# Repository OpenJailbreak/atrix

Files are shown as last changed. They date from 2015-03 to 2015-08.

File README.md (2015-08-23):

# Atrix v1.0.2
Atrix is an open source project based around iPhone/iPad/iPod 30pin to serial adapter or breakout hardware.

Two subprojects exsist;

Atrix half breakout - just gives you a small piece of hardware that just breaks out USB for sync and serial for uses such as on device kernel debugging. This is more of a BYOB (bring your own board) project as you'll need to provide your own serial converter such as an FTDI Basic, or the similar. 

Atrix full breakout (TODO) - gives you all 30 pins broken out just like a PodBreakout would.  

Atrix adapter - gives you everything you need in one package, FTDI and USB all on one board for convenience.

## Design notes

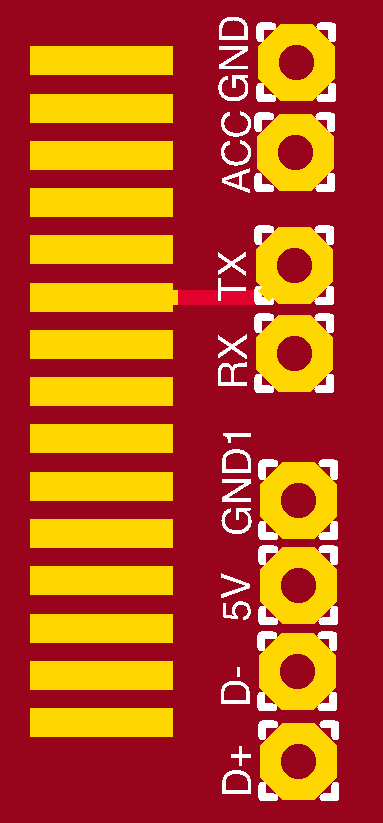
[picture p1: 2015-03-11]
breakout/mockups/Atrix_breakout_board_top.png

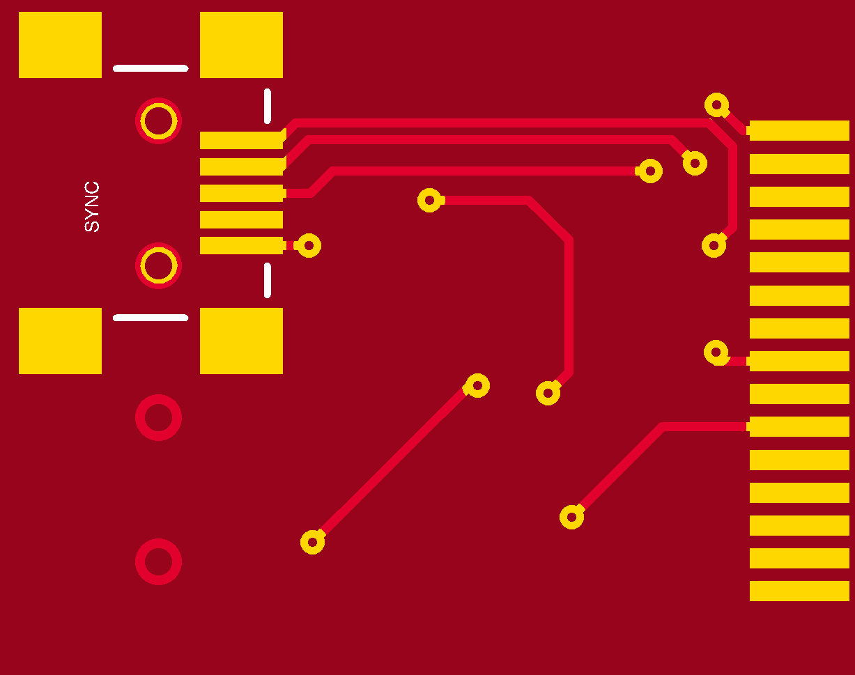
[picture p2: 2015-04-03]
adapter/mockups/eagleUp_Atrix_adapter_board_bottom.png

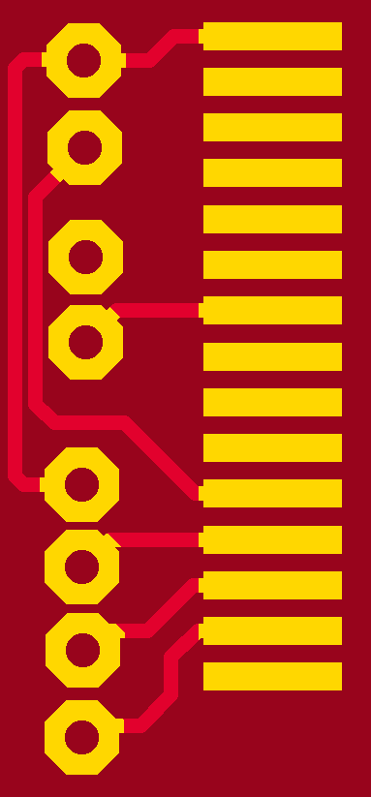
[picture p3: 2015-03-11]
breakout/mockups/Atrix_breakout_board_bottom.png

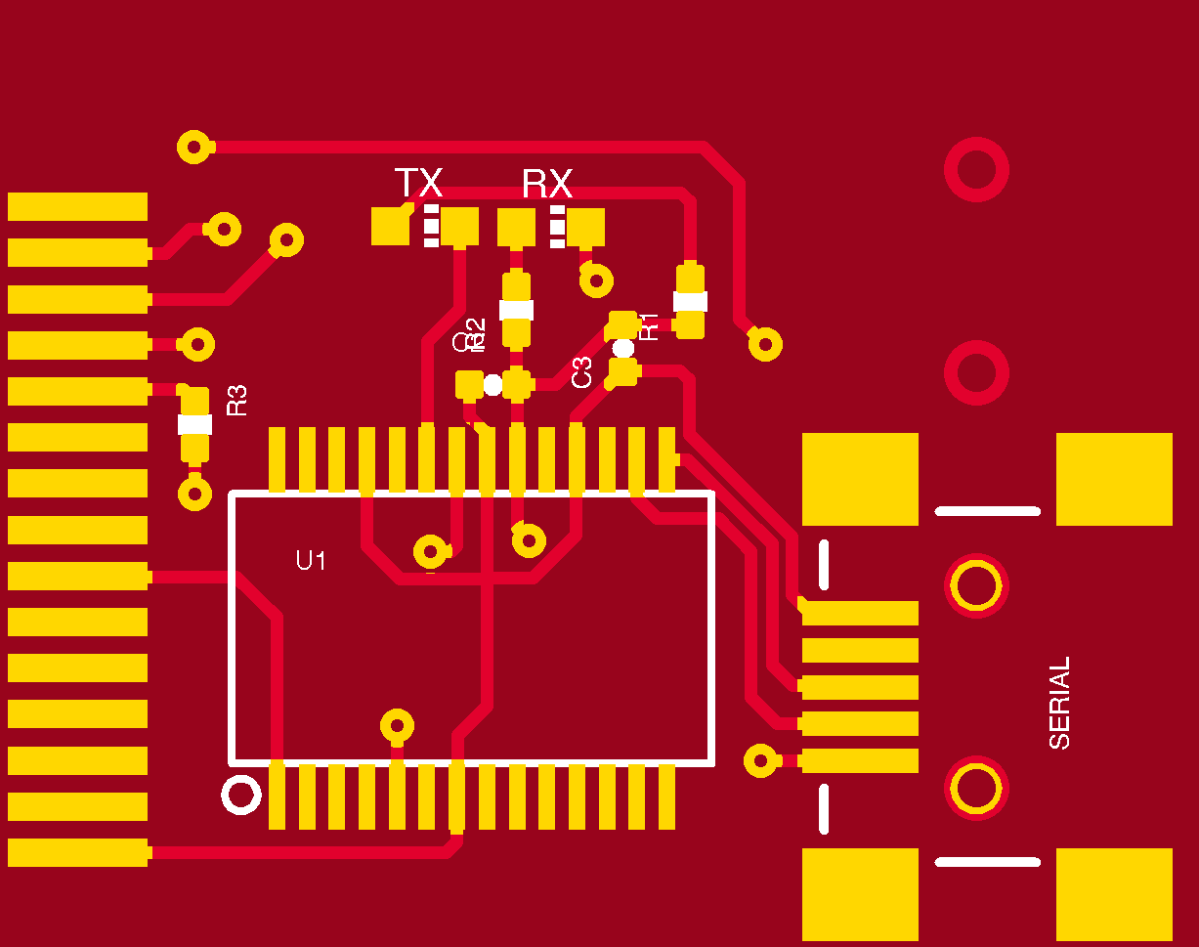
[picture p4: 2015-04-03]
adapter/mockups/eagleUp_Atrix_adapter_board_top.png

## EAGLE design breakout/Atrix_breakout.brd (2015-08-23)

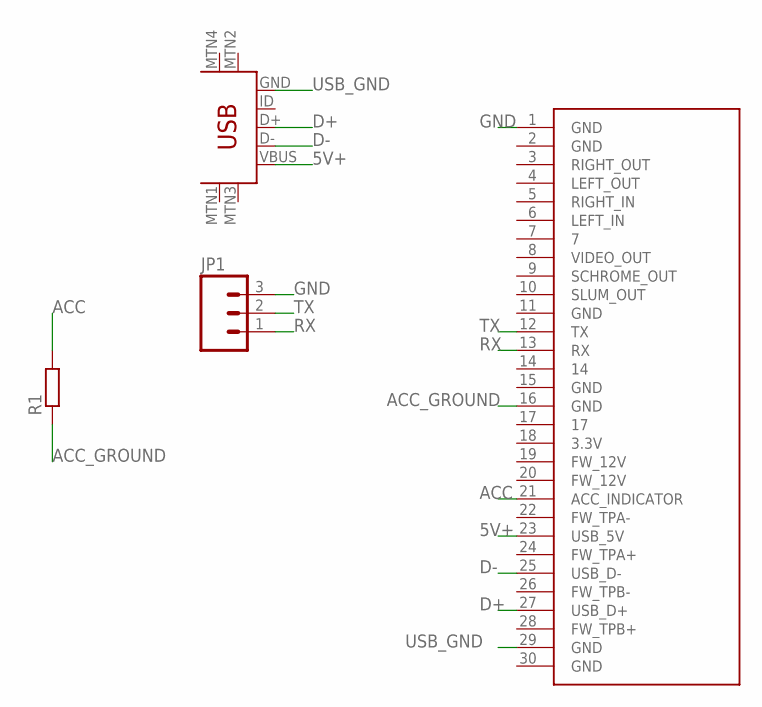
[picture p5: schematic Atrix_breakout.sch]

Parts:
JP1: M03; 03P
R1: R0207/10; 0207/10
U$1: IPOD_CONNECTOR_MALE; IPOD_MALE_CONNECTOR
U$3: USB-MINIB-5PIN; USB-MINIB

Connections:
5V+: U$1.23 (USB_5V), U$3.VBUS
ACC: R1.2, U$1.21 (ACC_INDICATOR)
ACC_GROUND: R1.1, U$1.16 (GND)
D+: U$1.27 (USB_D+), U$3.D+
D-: U$1.25 (USB_D-), U$3.D-
GND: JP1.3, U$1.1 (GND)
RX: JP1.1, U$1.13 (RX)
TX: JP1.2, U$1.12 (TX)
USB_GND: U$1.29 (GND), U$3.GND

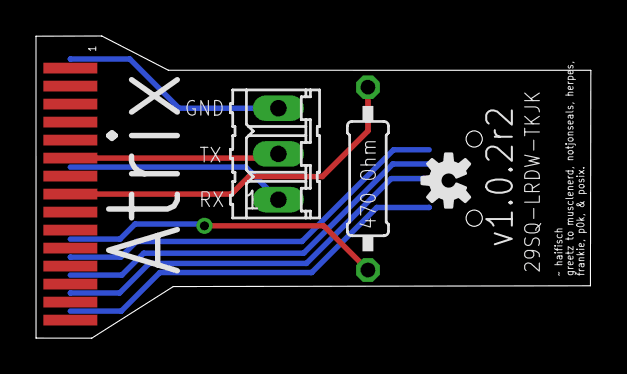
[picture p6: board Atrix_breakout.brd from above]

Board: 2 copper layers, 30.8 x 16.8 mm, 5 parts (1 on the bottom side), 9 nets.

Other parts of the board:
U$2: OSHW-LOGO-S

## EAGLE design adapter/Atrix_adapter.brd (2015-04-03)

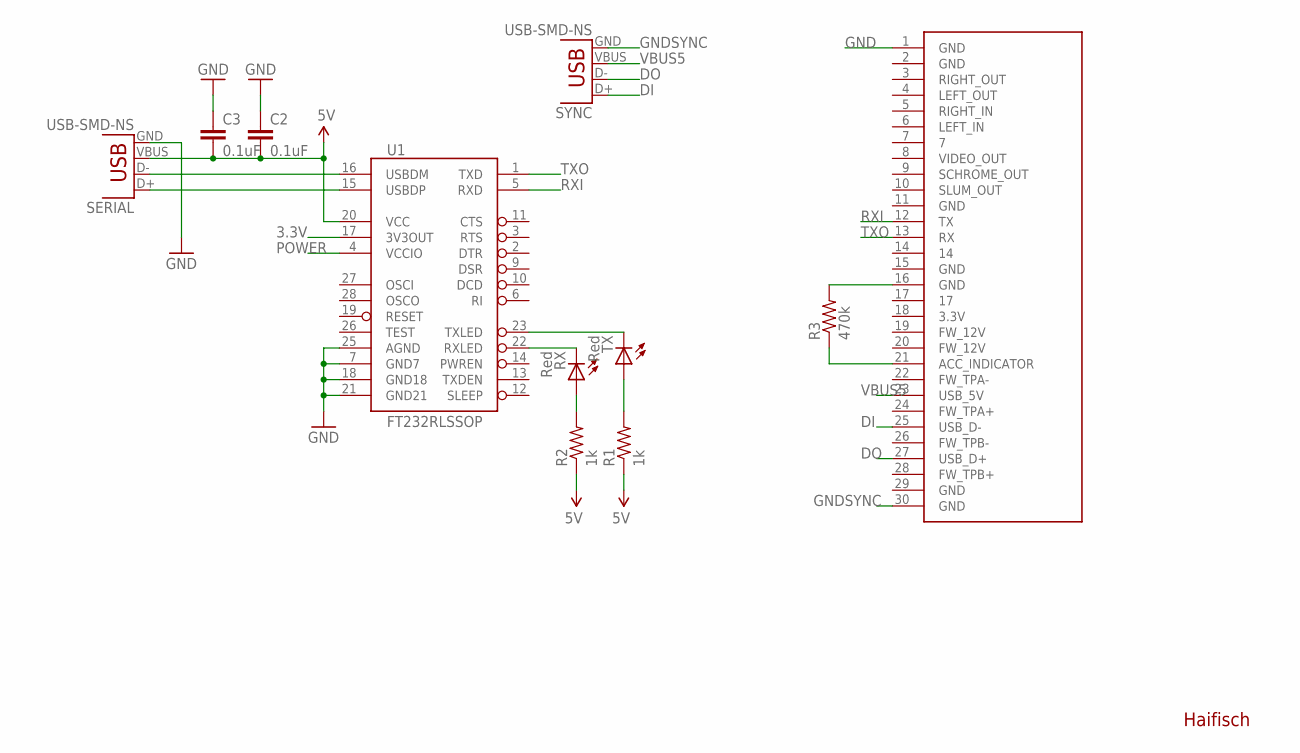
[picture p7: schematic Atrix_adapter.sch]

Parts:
C2, C3: 0.1uF; 0402-CAP
R1, R2: 1k; 0402-RES
R3: 470k; 0402-RES
RX: Red; CHIP-LED0603
SERIAL: USB-SMD-NS; USB-MINIB-NOSTOP
SYNC: USB-SMD-NS; USB-MINIB-NOSTOP
TX: Red; CHIP-LED0603
U1: FT232RLSSOP; SSOP28DB
U$1: IPOD_CONNECTOR_MALE; IPOD_MALE_CONNECTOR

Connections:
3.3V: U1.17 (3V3OUT)
5V: C2.2, C3.2, R1.1, R2.1, SERIAL.VBUS, U1.20 (VCC)
DI: SYNC.D+, U$1.25 (USB_D-)
DO: SYNC.D-, U$1.27 (USB_D+)
GND: C2.1, C3.1, SERIAL.GND, U1.7 (GND7), U1.18 (GND18), U1.21 (GND21), U1.25 (AGND), U$1.1 (GND)
GNDSYNC: SYNC.GND, U$1.30 (GND)
unnamed: R3.1, U$1.21 (ACC_INDICATOR)
unnamed: R3.2, U$1.16 (GND)
unnamed: SERIAL.D+, U1.15 (USBDP)
unnamed: SERIAL.D-, U1.16 (USBDM)
unnamed: R2.2, RX.A
unnamed: R1.2, TX.A
POWER: U1.4 (VCCIO)
RXI: U1.5 (RXD), U$1.12 (TX)
RXLED: RX.C, U1.22 (RXLED)
TXLED: TX.C, U1.23 (TXLED)
TXO: U1.1 (TXD), U$1.13 (RX)
VBUS5: SYNC.VBUS, U$1.23 (USB_5V)

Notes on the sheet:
Haifisch

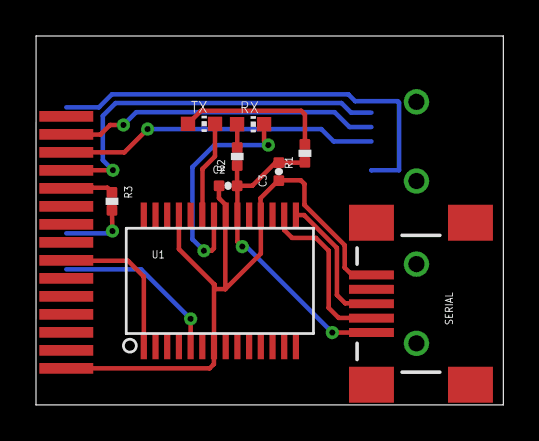
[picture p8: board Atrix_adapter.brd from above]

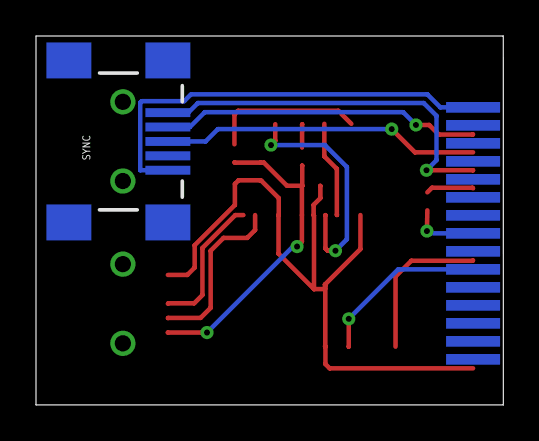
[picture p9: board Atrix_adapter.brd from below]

Board: 2 copper layers, 26.0 x 20.5 mm, 11 parts (2 on the bottom side), 16 nets.

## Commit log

2015-03-11 Change license to CERN OHL, Push eagle files
    [Atrix_breakout.brd, Atrix_breakout.sch]
2015-03-11 Update README with How-to
    [Atrix_breakout.brd, Atrix_breakout.sch]
2015-03-11 I lost track
2015-03-11 Correct AL pin name, should be ACC
    [Atrix_breakout.brd, Atrix_breakout.sch]
2015-04-03 Push to OpenJB
    [Atrix_breakout.brd, Atrix_breakout.sch, Atrix_breakout_v0_1.brd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]
2015-04-03 Move stuff around, update readme a bit
    [Atrix_adapter.brd, Atrix_adapter.sch, Atrix_breakout.brd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]
2015-04-03 Push current adapter board, create mockup, update readme a little
    [Atrix_adapter.brd, Atrix_adapter.sch, Atrix_breakout.brd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]
2015-06-13 Breakout updated to v1.0.1, improved board. See rev.txt
    [Atrix_breakout.brd, Atrix_breakout.sch]
2015-08-23 Rev v1.0.2r2
    [Atrix_breakout.brd, Atrix_breakout.sch]
2015-08-23 Add atrix labeling, improve existing serial labeling.
    [Atrix_breakout.brd]

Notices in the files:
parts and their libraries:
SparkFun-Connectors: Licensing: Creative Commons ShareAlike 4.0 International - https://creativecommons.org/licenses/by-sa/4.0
